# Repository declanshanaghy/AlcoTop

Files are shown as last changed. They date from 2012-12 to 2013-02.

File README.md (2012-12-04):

= AUTHOR::
Declan Shanaghy <declan@shanaghy.com>

= DESCRIPTION:
AlcoTop is the XMas drinking cap everyone should have.
With an alcohol sensor and lots of LED's you will know when
you haven't had enough to drink and your way home will be lit before you.

= REQUIREMENTS:
Arduino IDE for loading software onto the chip.
Eagle CAD 6.0+ for reading circuit schematic

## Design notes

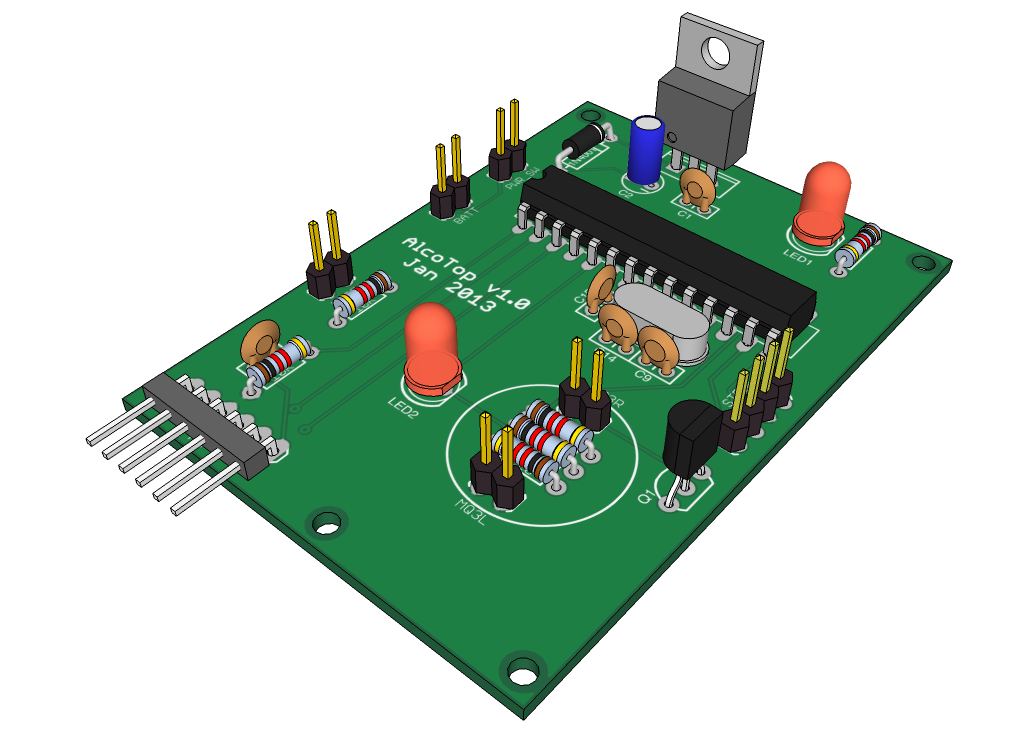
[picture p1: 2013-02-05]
AlcoTop.png

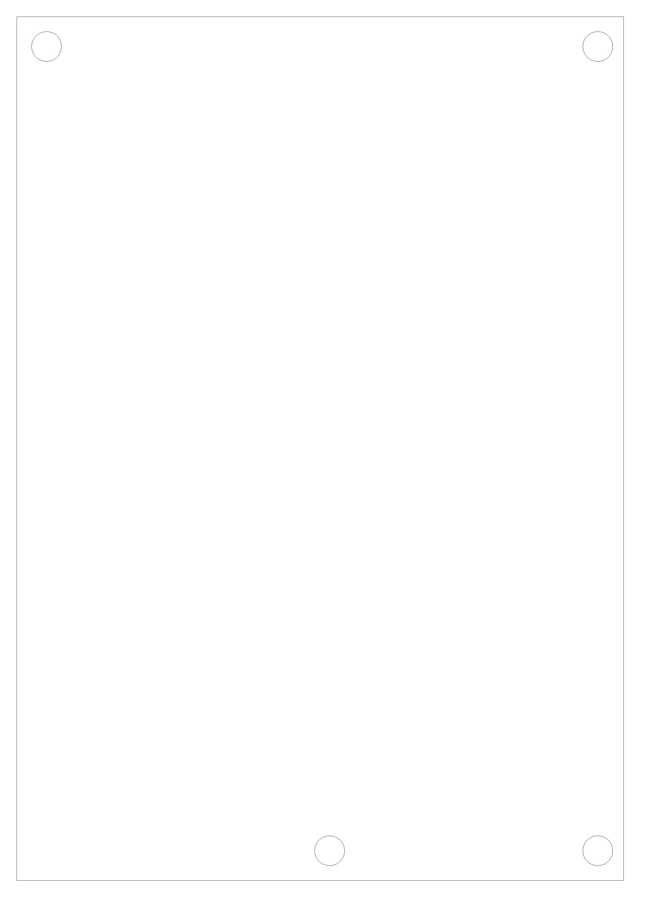
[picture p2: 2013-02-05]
eagleUp/eagleUp_AlcoTop_outline.png

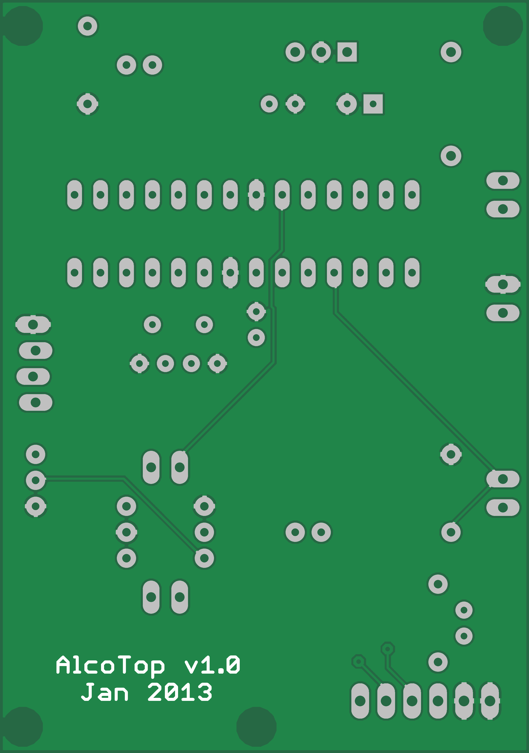
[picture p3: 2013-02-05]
eagleUp/eagleUp_AlcoTop_board_bottom.png

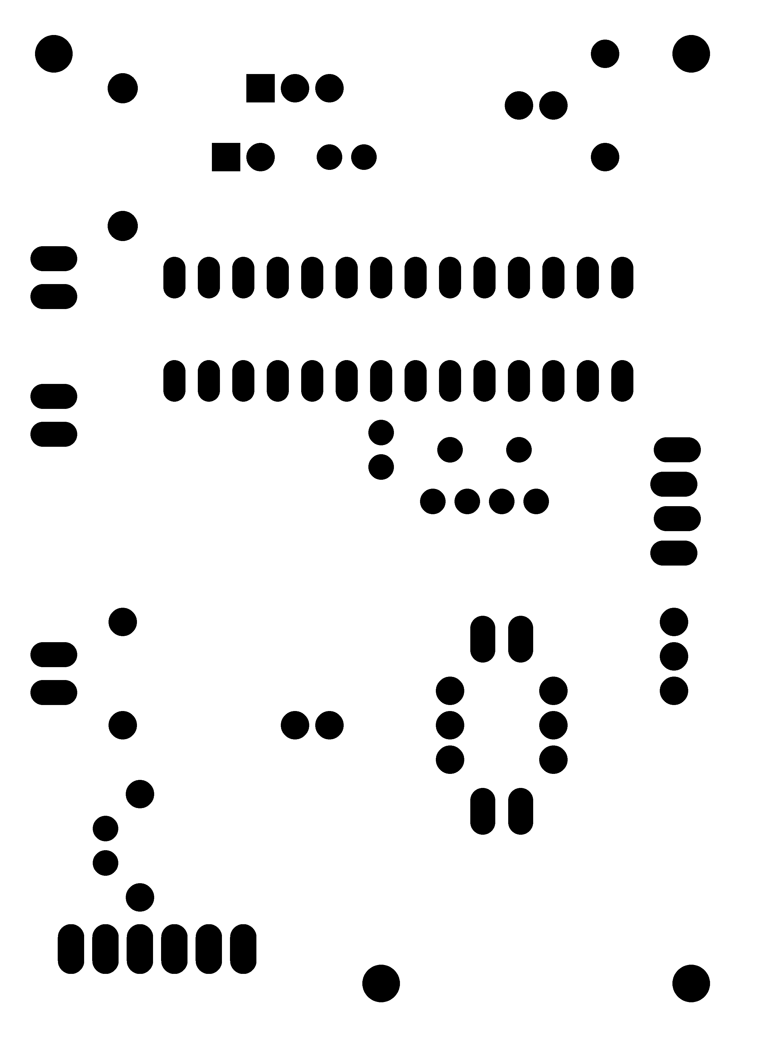
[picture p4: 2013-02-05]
eagleUp/eagleUp_AlcoTop_bottom_mask.png

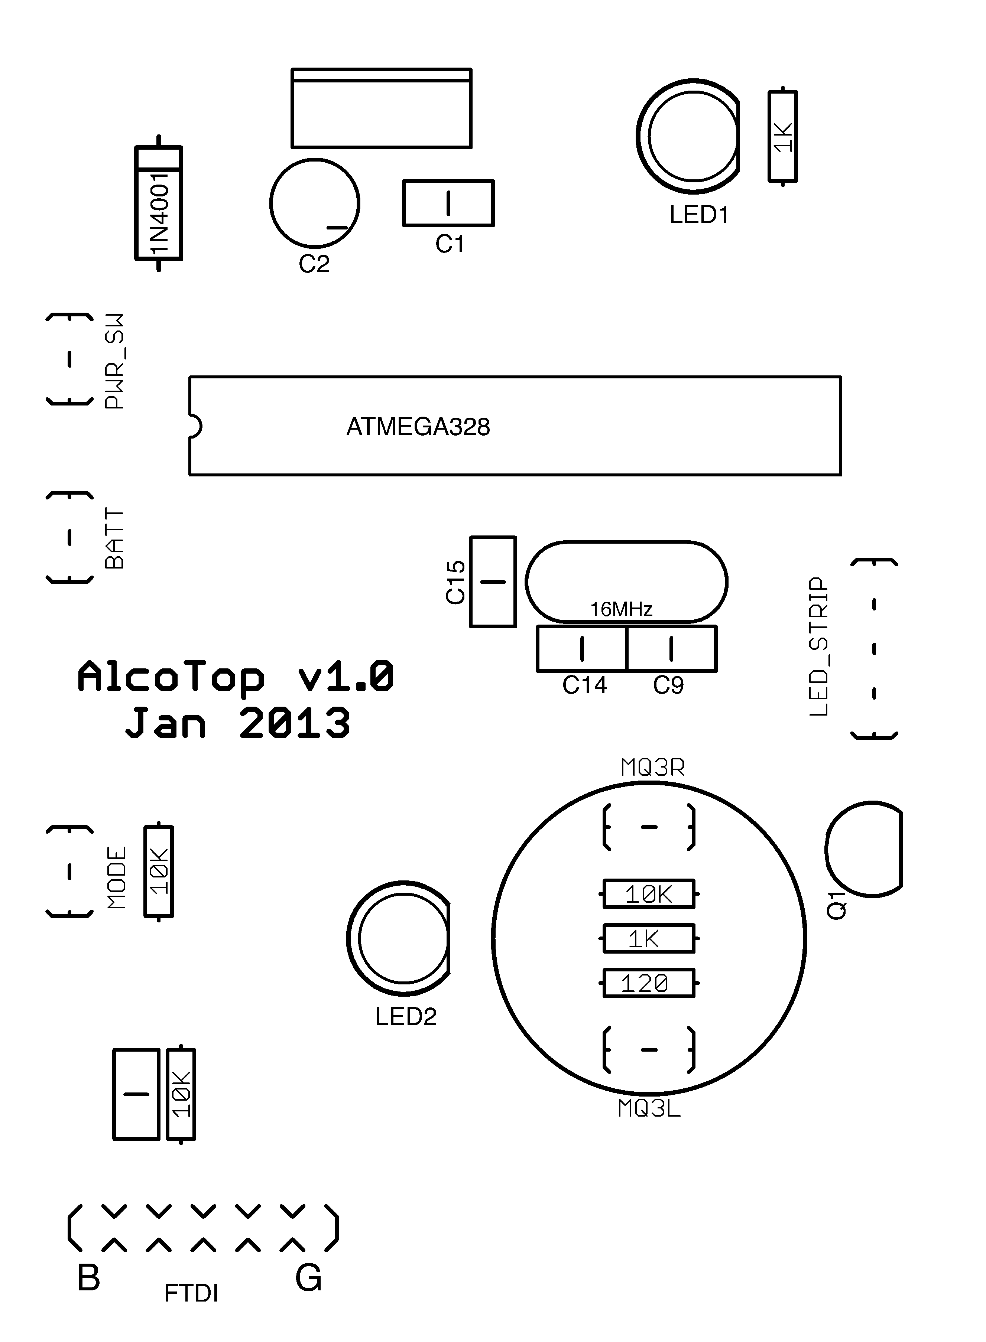
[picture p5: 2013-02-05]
eagleUp/eagleUp_AlcoTop_top_silk.png

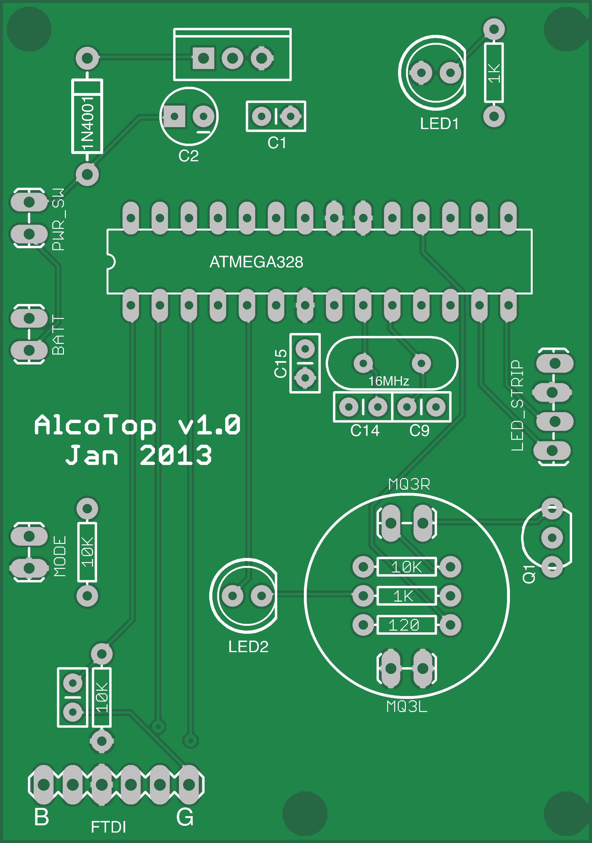
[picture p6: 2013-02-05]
eagleUp/eagleUp_AlcoTop_board_top.png

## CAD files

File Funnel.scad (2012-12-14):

funnel2();

//funnel1();

module funnel2() {
	difference() {
		union() {
			translate([0,0,24.5])
				cylinder(r=15, h=20);
			cylinder(r1=25, r2=15, h=25);
		}
		translate([0,0,-6])
			cylinder(r1=25, r2=10, h=35);
		cylinder(r=3.5, h=70);
	}
	translate([-16,-16,0])
		cube([32, 32, 0.5]);
}

module funnel1() {
	difference() {
		union() {
			translate([0,0,20])
				cylinder(r=5, h=20);
			difference() {
				#cylinder(r1=15, r2=1, h=35);
				translate([0,0,-5])
					cylinder(r1=15, r2=1, h=35);
				translate([-20,-20,25])
					cube(size = 40);
			}
		}
		translate([0,0,35])
			cylinder(r=2, h=10);
	}
}

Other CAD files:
AlcoTop.skp

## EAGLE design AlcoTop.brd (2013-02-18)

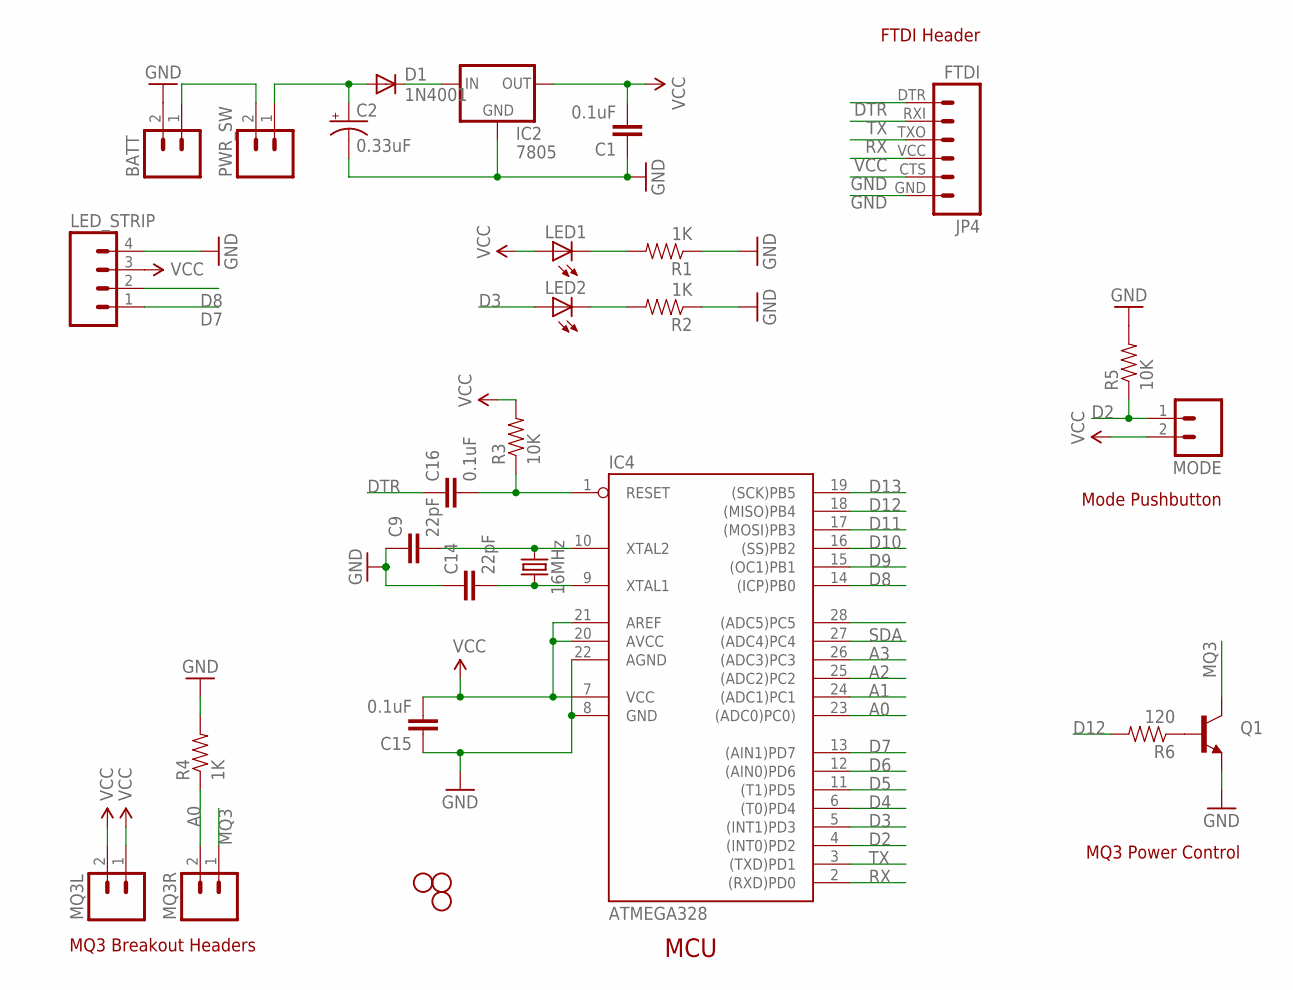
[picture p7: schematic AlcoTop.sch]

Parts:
BATT: M02LOCK_LONGPADS; 1X02_LOCK_LONGPADS
C1, C15, C16: 0.1uF; CAP-PTH-SMALL2
C2: 0.33uF; CPOL-RADIAL-10UF-25V
C9, C14: 22pF; CAP-PTH-SMALL2
D1: 1N4001; DIODE-1N4001
IC2: 7805; TO220-IGO
IC4: ATMEGA328; DIL28-3
JP1, JP2, JP6: STAND-OFF#2; STAND-OFF-#2
JP4: FTDI; FTDI_BASIC
LED1, LED2: LED5MM
LED_STRIP: M04LOCK_LONGPADS; 1X04_LOCK_LONGPADS
MODE: M02LOCK_LONGPADS; 1X02_LOCK_LONGPADS
MQ3L, MQ3R: M02LOCK_LONGPADS; 1X02_LOCK_LONGPADS
PWR_SW: M02LOCK_LONGPADS; 1X02_LOCK_LONGPADS
Q1: TRANSISTOR_NPNTO-92-AMMO; TO-92-AMMO
R1, R2, R4: 1K; AXIAL-0.3
R3, R5: 10K; AXIAL-0.3
R6: 120; AXIAL-0.3
Y1: 16MHz; HC49US

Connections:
A0: IC4.23 ((ADC0)PC0)), MQ3R.2, R4.P$1 (1)
A1: IC4.24 ((ADC1)PC1)
A2: IC4.25 ((ADC2)PC2)
A3: IC4.26 ((ADC3)PC3)
D2: IC4.4 ((INT0)PD2), MODE.1, R5.P$1 (1)
D3: IC4.5 ((INT1)PD3), LED2.A
D4: IC4.6 ((T0)PD4)
D5: IC4.11 ((T1)PD5)
D6: IC4.12 ((AIN0)PD6)
D7: IC4.13 ((AIN1)PD7), LED_STRIP.1
D8: IC4.14 ((ICP)PB0), LED_STRIP.2
D9: IC4.15 ((OC1)PB1)
D10: IC4.16 ((SS)PB2)
D11: IC4.17 ((MOSI)PB3)
D12: IC4.18 ((MISO)PB4), R6.P$2 (2)
D13: IC4.19 ((SCK)PB5)
DTR: C16.1, JP4.DTR (1)
GND: BATT.2, C1.1, C2.2 (-), C9.1, C14.1, C15.1, IC2.GND, IC4.8 (GND), IC4.22 (AGND), JP4.CTS (5), JP4.GND (6), LED_STRIP.4, Q1.1 (E), R1.P$1 (1), R2.P$1 (1), R4.P$2 (2), R5.P$2 (2)
MQ3: MQ3R.1, Q1.3 (C)
unnamed: LED1.K (C), R1.P$2 (2)
unnamed: BATT.1, PWR_SW.2
unnamed: C2.1 (+), D1.A, PWR_SW.1
unnamed: LED2.K (C), R2.P$2 (2)
unnamed: D1.C, IC2.IN
unnamed: Q1.2 (B), R6.P$1 (1)
RST: C16.2, IC4.1 (RESET), R3.P$1 (1)
RX: IC4.2 ((RXD)PD0), JP4.TXO (3)
SDA: IC4.27 ((ADC4)PC4)
TX: IC4.3 ((TXD)PD1), JP4.RXI (2)
VCC: C1.2, C15.2, IC2.OUT, IC4.7 (VCC), IC4.20 (AVCC), IC4.21 (AREF), JP4.VCC (4), LED1.A, LED_STRIP.3, MODE.2, MQ3L.1, MQ3L.2, R3.P$2 (2)
XTAL1: C14.2, IC4.9 (XTAL1), Y1.1
XTAL2: C9.2, IC4.10 (XTAL2), Y1.2

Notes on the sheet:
MCU
FTDI Header
Mode Pushbutton
MQ3 Power Control
MQ3 Breakout Headers

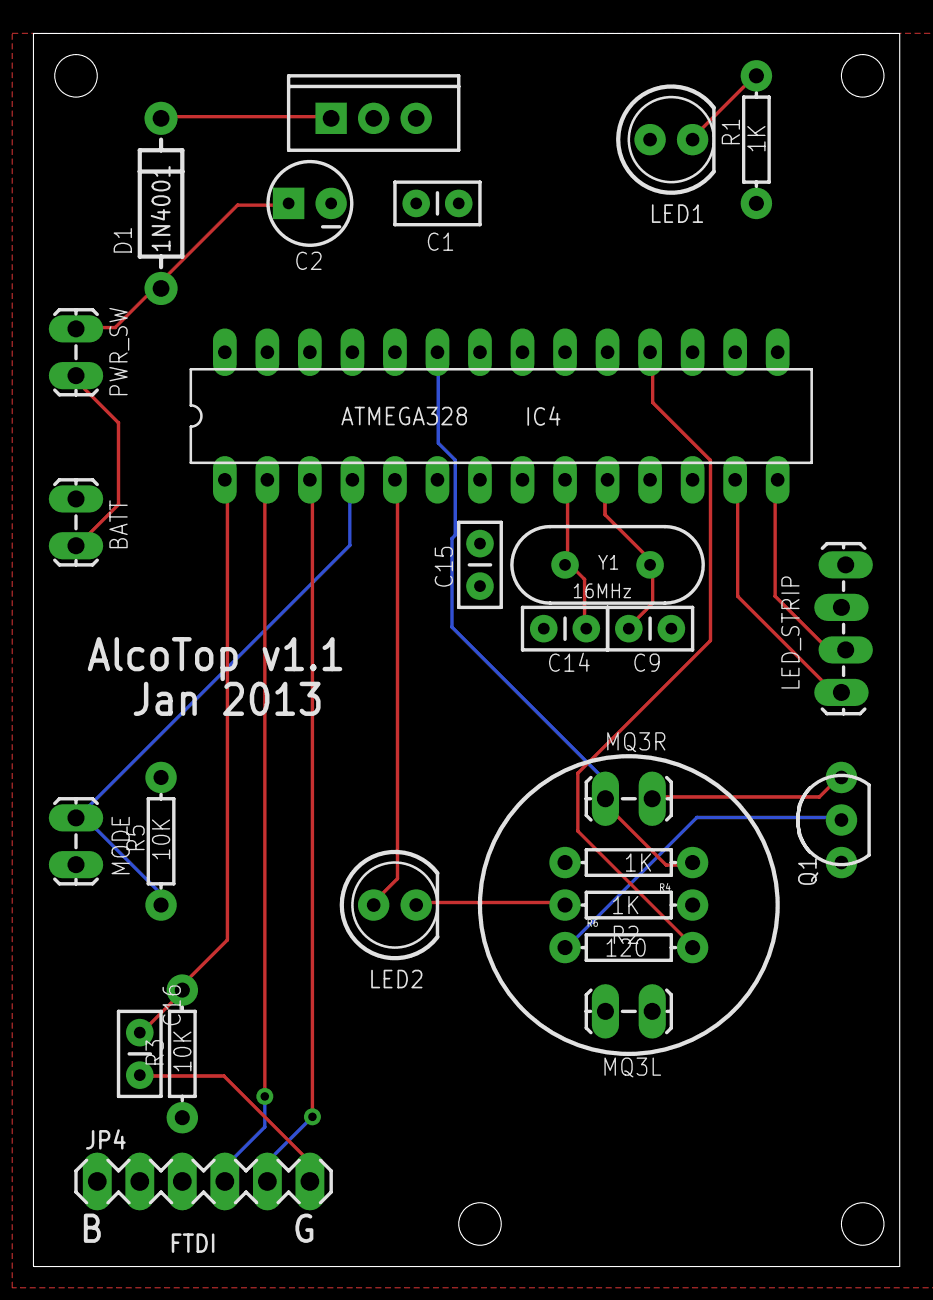
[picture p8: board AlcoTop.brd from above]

Board: 2 copper layers, 51.7 x 73.7 mm, 30 parts (0 on the bottom side), 21 nets.

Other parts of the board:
JP3: STAND-OFF#2; STAND-OFF-#2

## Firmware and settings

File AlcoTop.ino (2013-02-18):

#include <Bounce.h>

#include <TimerOne.h>
#include "LPD6803.h"

#define DBG 1

// Thresholds
#define ALCO_MIN_READ_ENABLE 75
#define ALCO_MIN_TRIGGER 250

//Absolute max that the sensor can reach when doused with isopropyl alcohol
#define MQ3_ABS_MAX 950  
// % of absolute max to use for scaling breath readings to the # of pixels
#define SCALE_READINGS 75
#define MQ3_MAX (MQ3_ABS_MAX / 100) * SCALE_READINGS

// Colors & speeeeeeds
//Number of bits used to represent a color
#define COLOR_BITS 3
//Number of color values of a single color
#define NUM_COLORS (1 << COLOR_BITS)
//Max color value 0 indexed
#define MAX_COLOR (NUM_COLORS - 1)
//Total color values in all 3 colors
#define NUM_RGB_COLORS (NUM_COLORS * 3)

//Slows down the rainbow when there are more bits in the colors
#define RAINBOW_SPEED 100 + ((5 - COLOR_BITS) * 25) 
#define RANDOM_SPEED 150
//Speed of the light wipe after a positive alcohol reading
#define GO_ALCO_SPEED 500
#define GO_ALCO_PAUSE 500
//Speed of the light flashes while waiting for a positive reading
#define INDICATE_ALCO_SPEED 350

// Some colors
#define COLOR_OFF Color(0, 0, 0)
#define COLOR_ALCO_WAIT Color(MAX_COLOR, 0, 0)
#define COLOR_ALCO_BUILDUP Color(MAX_COLOR, 0, MAX_COLOR)
#define COLOR_ALCO_GO Color(0, MAX_COLOR, 0)

//IO Pins
#define INDICATOR_LED 3
#define ALCO_BJT 12
#define ALCO_SENSOR A0
#define B_MODE 2
#define UNCONNECTED_ANALOG A5

#define N_PIXELS 20

//Even modes are light displays
#define MODE_RANDOM 0
#define MODE_RAINBOW 2
#define MODE_RAINBOWCYCLE 4

//All odd modes turn on the sensor
#define MODE_ALCO 1
#define MODE_MAX 6

// Choose which 2 pins you will use for output.
// Can be any valid output pins.
int dataPin = 7;       // 'yellow' wire
int clockPin = 8;      // 'green' wire

// Timer 1 is also used by the strip to send pixel clocks
// Set the first variable to the NUMBER of pixels. 20 = 20 pixels in a row

LPD6803 strip = LPD6803(N_PIXELS, dataPin, clockPin);
int alcoColors[N_PIXELS] = {0};

boolean bIsAlco = false;
boolean bAlcoUp = true;
boolean bReadAlco = false;
Bounce bMode = Bounce(B_MODE, 5);
uint8_t mode = 0;
uint32_t bLast = 0;
uint32_t tChangeMode = 0;
int32_t j = 0;
uint8_t k = 0;

void setup() {
#if DBG  
  Serial.begin(115200);
  Serial.println("Merry drinking!");
#endif

  // The Arduino needs to clock out the data to the pixels
  // this happens in interrupt timer 1, we can change how often
  // to call the interrupt. setting CPUmax to 100 will take nearly all all the
  // time to do the pixel updates and a nicer/faster display, 
  // especially with strands of over 100 dots.
  // (Note that the max is 'pessimistic', its probably 10% or 20% less in reality)  
  strip.setCPUmax(75);  // start with 50% CPU usage. up this if the strand flickers or is slow

  // Start up the LED counter
  strip.begin();

  calcAlcoColors();
  stripOff();

  pinMode(INDICATOR_LED, OUTPUT); 
  pinMode(ALCO_BJT, OUTPUT); 
  pinMode(ALCO_SENSOR, INPUT); 
  pinMode(B_MODE, INPUT); 

  (mode % 2 == 1) ? goAlco() : stopAlco();

  randomSeed(analogRead(UNCONNECTED_ANALOG));

  for ( uint8_t i=0; i<strip.numPixels(); i++ )
    randomStrip(0, i);
}


void loop() {
  bMode.update ();
  uint8_t oldMode = mode;

  int bRead = bMode.read();

  if (bRead == LOW && bLast == HIGH) {
    // Button was clicked, increment mode and loop 
    // around if max value is reached
    ++mode %= MODE_MAX;
#if DBG
    Serial.print("Mode changed to ");
    Serial.println(mode);
#endif
    j = 0;
    tChangeMode = millis();
    bIsAlco = false;
  }

  if ( mode % 2 == 1 ) {
    if ( oldMode != mode ) {
      goAlco();
    }
    else if ( ! bReadAlco ) {
      checkAlco();
    }
    else {
      if ( !processAlco() )
        indicateAlco();
    }
  }
  else {
    switch (mode) {
    case MODE_RANDOM:
      randomStrip(RANDOM_SPEED, -1);    
      if ( oldMode != mode )
        stopAlco();
      break;
    case MODE_RAINBOW:
      rainbow(RAINBOW_SPEED);
      if ( oldMode != mode )
        stopAlco();
      break;
    case MODE_RAINBOWCYCLE:
      rainbowCycle(RAINBOW_SPEED);
      if ( oldMode != mode )
        stopAlco();
      break;
    }
  }

  bLast = bRead;
}

void goAlco() {
  colorWipe(COLOR_ALCO_WAIT, 25, -1, -1, true);
  digitalWrite(ALCO_BJT, HIGH);
  j = -1;
#if DBG
  Serial.println("goAlco");
#endif
}

boolean processAlco() {
//#if DBG
//  Serial.println("processAlco");
//#endif
  int alco = bReadAlco ? readAlco() : 0;

  if ( alco < ALCO_MIN_TRIGGER ) {
    if ( bIsAlco ) {
      digitalWrite(INDICATOR_LED, LOW);
      bIsAlco = false;
    }
  }
  else {
    if ( ! bIsAlco ) {
      digitalWrite(INDICATOR_LED, HIGH);
      colorWipe(COLOR_OFF, 0, -1, -1, false);
      bIsAlco = true;
      bAlcoUp = true;
      j = 0;
      tChangeMode = millis();
    }
    int h = map(alco, 0, MQ3_MAX, 5, 20);
    showAlco(h);
  }

  return bIsAlco;
}

void indicateAlco() {
  uint32_t elapsed = millis() - tChangeMode;

//#if DBG
//  Serial.print("elapsed = ");
//  Serial.print(elapsed);
//  Serial.print("\tk = ");
//  Serial.println(k);
//#endif

  if ( elapsed < INDICATE_ALCO_SPEED / 2 ) {
    if ( k == 0 ) {
      colorWipe(COLOR_OFF, 0, -1, -1, false);
      k++;
//#if DBG
//      Serial.println("k == 0; k++");
//#endif
    }
  }
  else if ( elapsed < INDICATE_ALCO_SPEED ) {
    if ( k == 1 ) {
      colorWipe(COLOR_ALCO_GO, 0, -1, -1, false);
      k++;
      //#if DBG
      //  Serial.println("k == 1; k++");
      //#endif
    }
  }
  else if ( elapsed < INDICATE_ALCO_SPEED  * 1.5 ) {
    if ( k == 2 ) {
      colorWipe(COLOR_OFF, 0, -1, -1, false);
      k++;
      //#if DBG
      //  Serial.println("k == 2; k++");
      //#endif
    }
  }
  else if ( elapsed < INDICATE_ALCO_SPEED  * 2 ) {
    if ( k == 3 ) {
      colorWipe(COLOR_ALCO_GO, 0, -1, -1, false);
      k++;
      //#if DBG
      //  Serial.println("k == 3; k++");
      //#endif
    }
  }
  else if ( elapsed > INDICATE_ALCO_SPEED  * 6 ) {
    tChangeMode = millis();
    k = 0;
    //#if DBG
    //  Serial.println("k = 0; reset");
    //#endif
  }
}

void checkAlco() {
  int alco = readAlco();
//#if DBG
//  Serial.print("checkAlco");
//#endif

  if ( alco > ALCO_MIN_READ_ENABLE ) {
    bReadAlco = true;
    tChangeMode = millis();
    k = 0;
#if DBG
    Serial.println("bReadAlco = true");
#endif
  }
  else {
    int i = map(alco, 0, ALCO_MIN_READ_ENABLE, 0, 20);
    if ( i != j ) {
      j = i;
      colorWipe(COLOR_ALCO_BUILDUP, 0, -1, j, true);
//#if DBG
//  Serial.print("checkAlco: ");
//  Serial.println(j);
//#endif
      delay(50);
    }
  }
}

void stopAlco() {
  digitalWrite(ALCO_BJT, LOW);
  bReadAlco = false;
#if DBG
  Serial.println("stopAlco");
#endif
}

void stripOff() {
  for (uint8_t i=0; i < strip.numPixels(); i++) {
    strip.setPixelColor(i, Color(31, 31, 0));
  }
  strip.show();
}

void calcAlcoColors() {
  int8_t mid = 8;
  int16_t step = NUM_COLORS / mid;
  if ( step == 0 )
    step = 1;
  int16_t r = 0, g = MAX_COLOR;

  for (int8_t i=0; i < mid; i++) {
//#if DBG    
//  Serial.print("i="); Serial.print(i);
//  Serial.print(", r="); Serial.print(r);
//  Serial.print(", g="); Serial.println(g);
//#endif

    alcoColors[i] = Color(r, g, 0);    

    r += step;
    if ( r > MAX_COLOR )
      r = MAX_COLOR;
  }

  for (uint8_t i=mid; i < 20; i++) {
//#if DBG    
//  Serial.print("i="); Serial.print(i);
//  Serial.print(", r="); Serial.print(r);
//  Serial.print(", g="); Serial.println(g);
//#endif

    alcoColors[i] = Color(r, g, 0);    

    g -= step;
    if ( g < 0 )
      g = 0;      
  }
}

void showAlco(int h) {
  long elapsed = millis() - tChangeMode;
  int perPixel = GO_ALCO_SPEED / h;

  if ( elapsed >  perPixel ) {
//#if DBG
//  Serial.print("elapsed = ");
//  Serial.println(elapsed);
//  Serial.print("perPixel = ");
//  Serial.println(perPixel);
//#endif
//#if DBG
//  Serial.print("bAlcoUp = ");
//  Serial.println(bAlcoUp);
//  Serial.print("j = ");
//  Serial.println(j);
//#endif

    if ( bAlcoUp ) {
      // Pause at the top
      if ( j == h + 1 ) {
        if ( elapsed >  GO_ALCO_PAUSE ) {
          bAlcoUp = false;
          tChangeMode = millis();
        }        
      }
      else {
        strip.setPixelColor(j, alcoColors[j]);
        strip.show();

        tChangeMode = millis();
        bAlcoUp = j++ <= h;
      }
    }
    else {
      strip.setPixelColor(j, COLOR_OFF);
      strip.show();
      bAlcoUp = j-- < 0;
      tChangeMode = millis();      
    }    
  }
}

int readAlco() {
  int alco = analogRead(ALCO_SENSOR);

#if DBG
  Serial.print("alco = ");
  Serial.println(alco);
  delay(25);
#endif
 
  return alco;
}

void randomStrip(int wait, int index) {
  if ( index < 0 )
    index = random(0, strip.numPixels());

  //#if DBG
  //  Serial.print("randomStrip: ");
  //  Serial.println(index);
  //#endif

  int r = 0, g = 0, b = 0;
  int mix = random(0, 2);
  switch ( mix ) {
  case 0:
    r = random(0, MAX_COLOR);
    g = random(0, MAX_COLOR);
    break;
  case 1:
    g = random(0, MAX_COLOR);
    b = random(0, MAX_COLOR);
    break;
  case 2:
    r = random(0, MAX_COLOR);
    b = random(0, MAX_COLOR);
    break;
  }

  strip.setPixelColor(index, Color(r, g, b));
  strip.show();
  if ( wait > 0 )
    delay(wait);
}

void rainbow(uint8_t wait) {
  //#if DBG
  //  Serial.print("rainbow: ");
  //  Serial.println(j);
  //#endif
  for (uint8_t i=0; i < strip.numPixels(); i++) {
    strip.setPixelColor(i, Wheel((i + j) % NUM_RGB_COLORS));
  }  
  strip.show();   // write all the pixels out
  delay(wait);

  if ( j++ > NUM_RGB_COLORS * 3 ) {
    // 3 cycles of all NUM_RGB_COLORS colors in the wheel
    j = 0;
  }
}

void rainbowCycle(uint8_t wait) {
  //#if DBG
  //  Serial.print("rainbowCycle: ");
  //  Serial.println(j);
  //#endif
  for (uint8_t i=0; i < strip.numPixels(); i++) {
    // tricky math! we use each pixel as a fraction of the full NUM_RGB_COLORS-color wheel
    // (thats the i / strip.numPixels() part)
    // Then add in j which makes the colors go around per pixel
    // the % NUM_RGB_COLORS is to make the wheel cycle around
    strip.setPixelColor(i, Wheel( ((i * NUM_RGB_COLORS / strip.numPixels()) + j) % NUM_RGB_COLORS)  );
  }  
  strip.show();   // write all the pixels out
  delay(wait);

  if ( j++ > NUM_RGB_COLORS * 5 ) {
    // 5 cycles of all NUM_RGB_COLORS colors in the wheel
    j = 0;    
  }
}

// fill the dots one after the other with said color
// good for testing purposes
void colorWipe(uint16_t c, uint8_t wait, uint8_t start, uint8_t finish, boolean up) {
  //#if DBG
  //  Serial.print("colorWipe: ");
  //  Serial.println(c);
  //#endif
  if ( up ) {
    if ( start < 0 || start > strip.numPixels() ) 
      start = 0;
    if ( finish < 0 || finish > strip.numPixels() ) 
      finish = strip.numPixels();

    for (int i=start; i < finish; i++) {
      strip.setPixelColor(i, c);
      if ( wait > 0 ) {
        strip.show();
        delay(wait);
      }
    }
  }
  else {
    if ( start < 0 || start > strip.numPixels() - 1 )
      start = strip.numPixels() - 1;
    if ( finish < 0 || finish > strip.numPixels() - 1 )
      finish = 0;

    for (int i=start; i >= finish; i--) {
      strip.setPixelColor(i, c);
      if ( wait > 0 ) {
        strip.show();
        delay(wait);
      }
    }
  }

  if ( wait == 0 ) {
    strip.show();
  }
}

/* Helper functions */

// Create a 15 bit color value from R,G,B
unsigned int Color(byte r, byte g, byte b)
{
  //Take the lowest 5 bits of each value and append them end to end
  return( (((unsigned int)g & 0x1F) << 10) | (((unsigned int)b & 0x1F) << 5) | ((unsigned int)r & 0x1F) );
}

//Input a value 0 to 127 to get a color value.
//The colours are a transition r - g -b - back to r
unsigned int Wheel(byte WheelPos)
{
  byte r=0, g=0, b=0;
  switch(WheelPos >> COLOR_BITS)
  {
  case 0:
    r = MAX_COLOR - WheelPos % NUM_COLORS;   //Red down
    g = WheelPos % NUM_COLORS;      // Green up
    b = 0;                  //blue off
    break; 
  case 1:
    g = MAX_COLOR - WheelPos % NUM_COLORS;  //green down
    b = WheelPos % NUM_COLORS;      //blue up
    r = 0;                  //red off
    break; 
  case 2:
    b = MAX_COLOR - WheelPos % NUM_COLORS;  //blue down 
    r = WheelPos % NUM_COLORS;      //red up
    g = 0;                  //green off
    break; 
  }
  return(Color(r,g,b));
}

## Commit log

2012-12-04 Initial implementation
    [AlcoTop.brd, AlcoTop.sch]
2012-12-05 Added transistor switch for MQ3 and pushbutton to change mode. 100mA operating current. YAY
    [AlcoTop.brd, AlcoTop.sch]
2012-12-07 Switch mode with a single button press. Modes are: random, alco, rainbow, alco, rainbow cycle, alco
2012-12-12 Added funnel and alco read mode on every second click
    [Funnel.scad]
2012-12-13 Add ability to read the button while taking alcohol readings
2012-12-13 Fixed bug which prevented subsequent readings after changing beyond mode 2
    [AlcoTop.ino]
2012-12-14 Added mouthpiece funnel. Fixed weirdness in alco sensor readings. Liquid insulator on the 2222PNP was causing it
    [Funnel.scad]
2013-02-05 Updated board
    [AlcoTop.brd, AlcoTop.sch, AlcoTop.skp]
2013-02-18 Reduced MQ3 voltage divider resistor to 1K
    [AlcoTop.brd, AlcoTop.sch]
2013-02-18 Bumped version to 1.1
    [AlcoTop.brd]
2013-02-18 Tweaked thresholds for 1K resistor

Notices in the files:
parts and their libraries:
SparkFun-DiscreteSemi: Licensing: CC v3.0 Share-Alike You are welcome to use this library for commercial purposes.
